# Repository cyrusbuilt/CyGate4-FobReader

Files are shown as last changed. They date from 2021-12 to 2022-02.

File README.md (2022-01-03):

# CyGate4-FobReader

Proximity Fob/Card reader add-on for CyGate4

## Synopsis

This is a proximity fob/card reader add-on for [CyGate4](https://github.com/cyrusbuilt/CyGate4).  It is designed to be a carrier board for the the [MiFare RC522](https://www.sunfounder.com/products/rfid-kit-red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). This device can read all fobs/cards supported by the MiFare MFRC522 and connects to the CyGate4 over I2C (aka 2-wire) bus. It can be powered by the CyGate4 itself or via an external 5VDC supply. This board can store up to 5 scanned cards in memory before overwriting the oldest scans. As scanned cards are read from the controller, they are removed from the buffer. Support for the CyGate4 Fob Reader is built-in to the CyGate4 firmware. This board uses a 7bit addressing scheme that allows up to 8 readers to be attached to a single CyGate4 at any given time. As long as the address is configured appropriately, they will be auto-detected and initialized during CyGate4's boot cycle.

## Operation

On power-up, the PWR LED will turn on and the device will immediately boot and log debug messages to the serial console. It will make itself available on the I2C bus (if connected) at the configured address. Presenting a MiFare-comptible prox card/fob will trigger a read. If a valid read occurs, the tag will be stored in memory.  When the read occurs, the ACT LED will flash once and the piezo will beep once.  This will happen whether it is connected to a CyGate4 host or not. If the tag sent to CyGate4 is determined to be invalid, it will send a command back indicating a bad card which will cause this reader to beep and flash 3 times in ~1 second.

## Configuration

The board has 3 jumpers (J4 - J6) that are used to configure the I2C bus address. Each jumper *MUST* be jumpered to either (+) (binary 1) or (-) (binary 0) and cannot be left open. The 3 values are bit-OR'ed together along with an address offset to compute the bus address.

## Command Set and Communication Protocol

The following commands can be sent to the device and will return a response. Since I have not timed each of the responses yet,
so as a general rule of thumb, I would allow at least 10ms between sending the command and expecting the response.

```
DETECT = 0xFA
INIT = 0xFB
GET_FIRMWARE = 0xFC
SELF_TEST = 0xDC
GET_TAGS = 0xFD
GET_AVAILABLE = 0xFE
BAD_CARD = 0xDD
GET_MIFARE_VERSION = 0xDB
```

DETECT: Asks the reader to identify itself. Sends back a one-byte ACK response if present: (DETECT_ACK = 0xDA).

INIT: Instructs the reader to initialize itself. Currently, this will only return a command ACK (INIT = 0xFB).

GET_FIRMWARE: This instructs the reader to report it's firmware version which will send the following packet:

```
Byte 0 = ACK (GET_FIRMWARE = 0xFC)
Byte 1 = Version length (# of bytes representing version string)
Byte 2 - n = The version string
```

SELF_TEST: Instructs the reader to perform a self-test. This will return a packet containing self-test result:

```
Byte 0 = ACK (SELF_TEST = 0xDC)
Byte 1 = Result (1 = Pass, 0 = Fail)
```

GET_TAGS: Instructs the reader to return any tags it has stored in memory (currently limited to 1 (the most recent) but will be up to 5 in the future). This will return the following packet data:

```
Byte 0 = ACK (GET_TAGS = 0xFD)
Byte 1 = Record count (1)
Byte 2 = Tag length in bytes (up to 10)
Byte 3 - 13 = Tag serial number (right-padded with 0xFF)
```

GET_AVAILABLE: Instructs the reader to indicate whether or not any tags are present. Sends back the following packet:

```
Byte 0 = ACK (GET_AVAILABLE = 0xFE)
Byte 1 = Result (1 = Available, 0 = No tags)
```

BAD_CARD: Instructs the reader to signal to the user that a bad card was presented (access denied). Sends back a one-byte ACK (BAD_CARD = 0xDD).

GET_MIFARE_VERSION: Instructs the reader to return the MiFare RFID reader version. Sends back the following packet:

```
Byte 0 = ACK (GET_MIFARE_VERSION = 0xDB)
Byte 1 = MiFare version (ie. 0x92)
```

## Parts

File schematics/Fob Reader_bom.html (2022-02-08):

Label | Part Type | Properties
Arduino Micro | Arduino Micro (Rev3) | type Arduino Micro (Rev3)
J1 | Generic female header - 8 pins | hole size 1.0mm,0.508mm; pins 8; form ♀ (female); package THT; pin spacing 0.1in (2.54mm); row single
J2 | Screw terminal - 4 pins | hole size 1.0mm,0.508mm; pins 4; package THT; pin spacing 0.137in (3.5mm)
J3 | Piezo Speaker
J4 | Generic male header - 3 pins | hole size 1.0mm,0.508mm; pins 3; form ♂ (male); package THT; pin spacing 0.1in (2.54mm); row single
J5 | Generic male header - 3 pins | hole size 1.0mm,0.508mm; pins 3; form ♂ (male); package THT; pin spacing 0.1in (2.54mm); row single
J6 | Generic male header - 3 pins | hole size 1.0mm,0.508mm; pins 3; form ♂ (male); package THT; pin spacing 0.1in (2.54mm); row single
J7 | Generic female header - 4 pins | hole size 1.0mm,0.508mm; pins 4; form ♀ (female); package THT; pin spacing 0.1in (2.54mm); row single
J8 | Generic female header - 4 pins | hole size 1.0mm,0.508mm; pins 4; form ♀ (female); package THT; pin spacing 0.1in (2.54mm); row single
LED1 | Red (633nm) LED | color Red (633nm); leg yes; package 5 mm [THT]
LED2 | Green (570nm) LED | color Green (570nm); leg yes; package 5 mm [THT]
Part2 | Schematic Frame | sheet 1/1; date 1609690318; project CyGate4 - Fob Reader; rev 2.0; filename Fob Reader.fzz; descr Proximity Fob Reader for CyGate4
Amount | Part Type | Properties
1 | Arduino Micro (Rev3) | type Arduino Micro (Rev3)
1 | Generic female header - 8 pins | hole size 1.0mm,0.508mm; pins 8; form ♀ (female); package THT; pin spacing 0.1in (2.54mm); row single
1 | Screw terminal - 4 pins | hole size 1.0mm,0.508mm; pins 4; package THT; pin spacing 0.137in (3.5mm)
1 | Piezo Speaker
3 | Generic male header - 3 pins | hole size 1.0mm,0.508mm; pins 3; form ♂ (male); package THT; pin spacing 0.1in (2.54mm); row single
2 | Generic female header - 4 pins | hole size 1.0mm,0.508mm; pins 4; form ♀ (female); package THT; pin spacing 0.1in (2.54mm); row single
1 | Red (633nm) LED | color Red (633nm); leg yes; package 5 mm [THT]
1 | Green (570nm) LED | color Green (570nm); leg yes; package 5 mm [THT]
1 | Schematic Frame | sheet 1/1; date 1609690318; project CyGate4 - Fob Reader; rev 2.0; filename Fob Reader.fzz; descr Proximity Fob Reader for CyGate4

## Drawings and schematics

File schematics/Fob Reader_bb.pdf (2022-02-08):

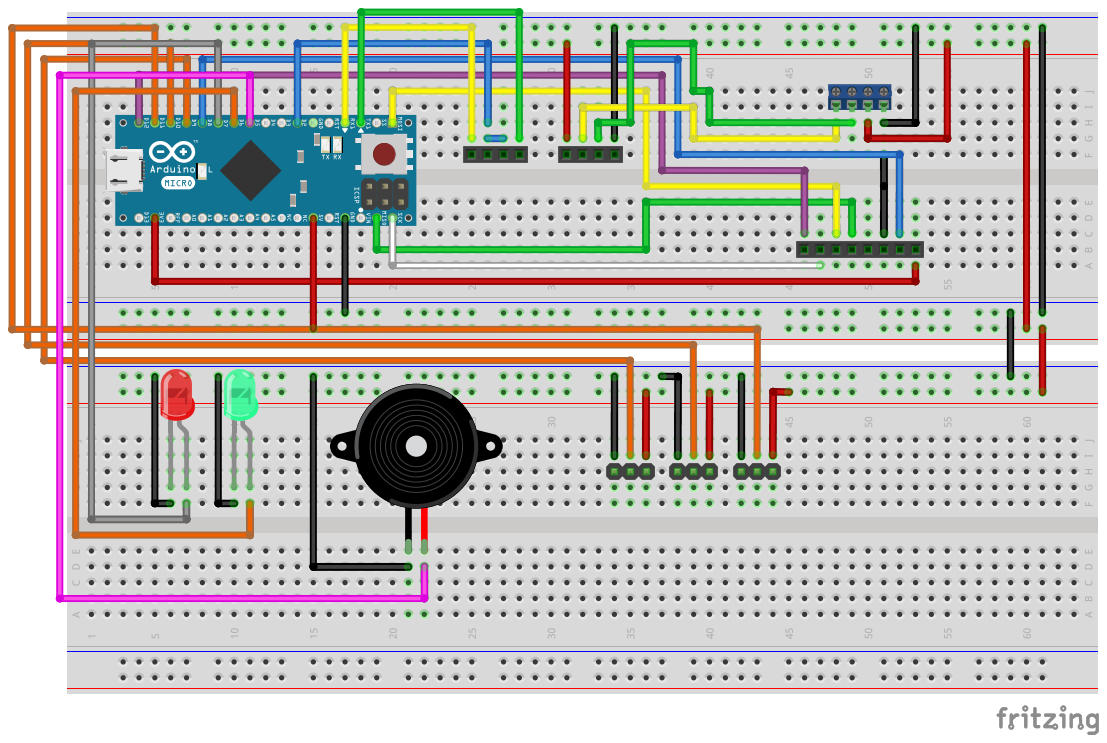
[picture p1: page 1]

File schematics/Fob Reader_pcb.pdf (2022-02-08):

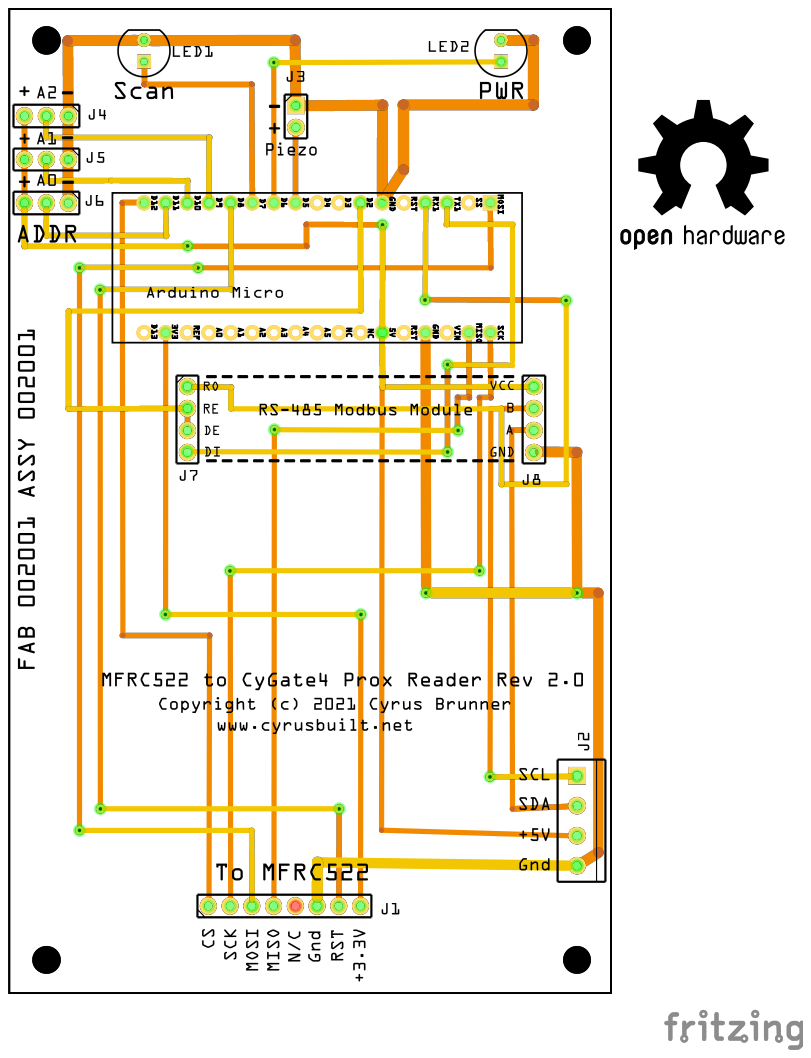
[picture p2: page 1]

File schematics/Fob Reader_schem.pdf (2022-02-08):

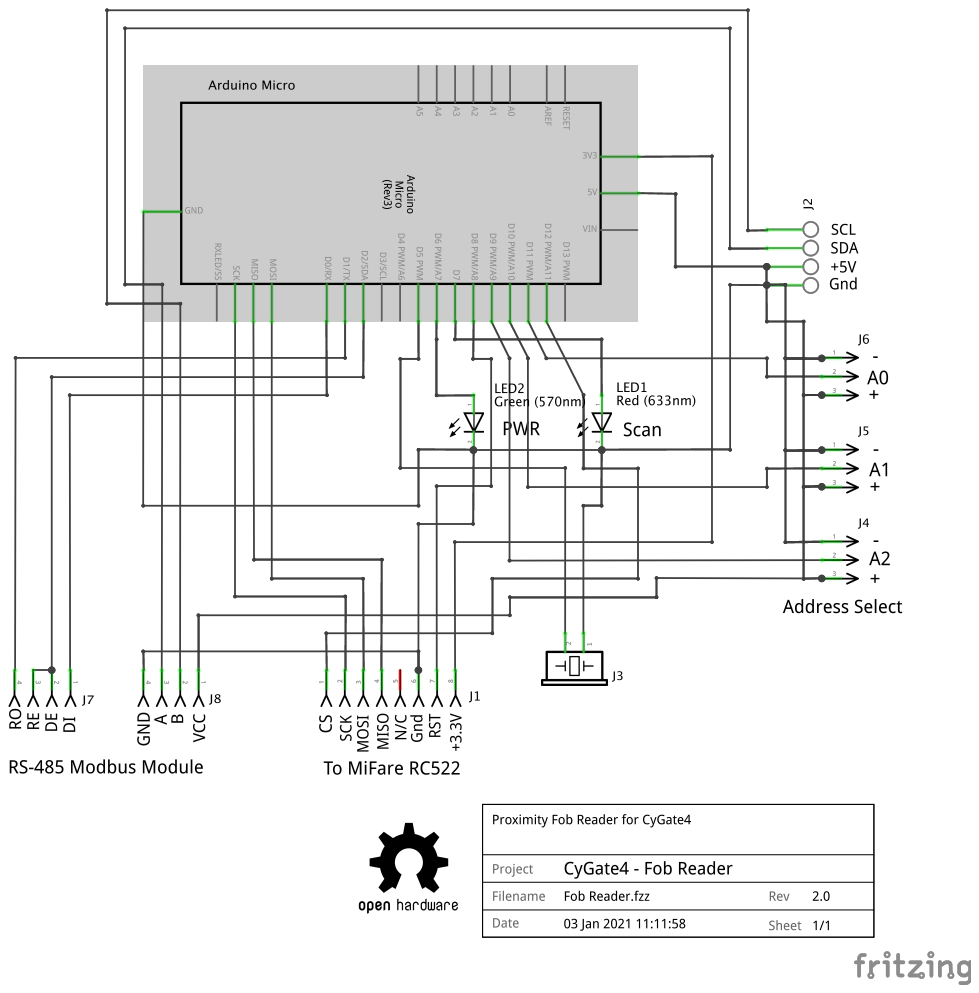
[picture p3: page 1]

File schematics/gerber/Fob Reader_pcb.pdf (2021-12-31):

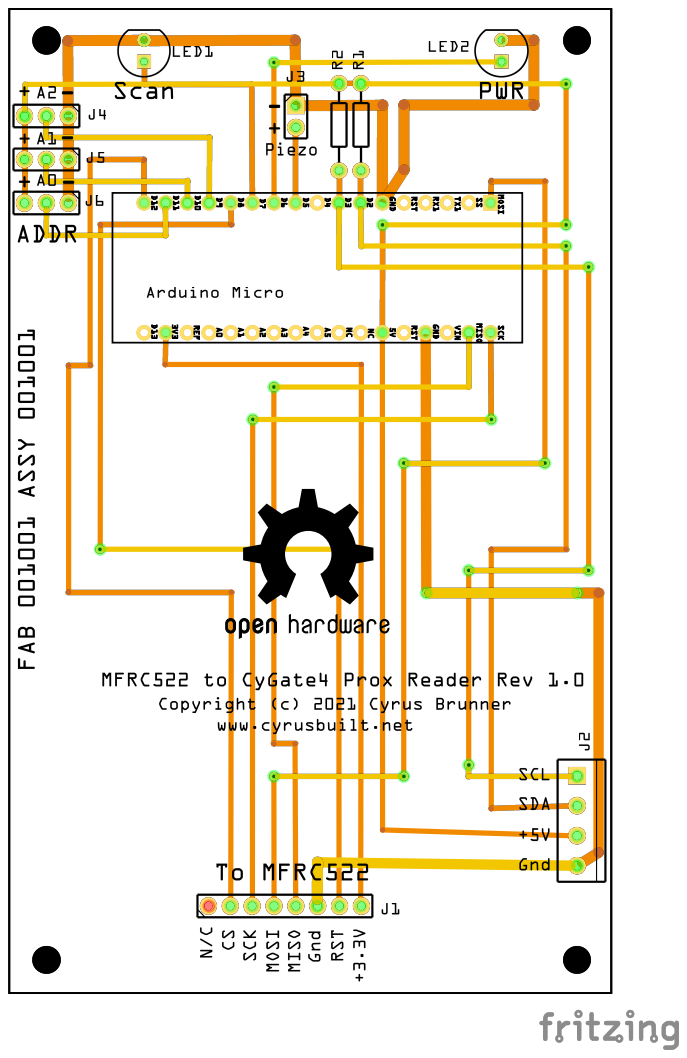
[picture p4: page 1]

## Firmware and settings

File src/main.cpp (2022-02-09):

/**
 * @file main.cpp
 * @author cyrus (cyrusbuilt at gmail dot com)
 * @brief Firmware for CyGate4 - Fob Reader.  Intended to run on the Arduino
 * Micro Rev3. Works with MiFare MFRC522 RFID readers and is intended to
 * interface with the CyGate4 over I2C.
 * @version 1.0
 * @date 2021-12-31
 * 
 * @copyright Copyright (c) Cyrus Brunner 2021
 * 
 */

#include <Arduino.h>
#include <SPI.h>
#include "LED.h"
#include "Buzzer.h"
#include "MFRC522.h"
#include "Modbus.h"

#define FIRMWARE_VERSION "1.0"

#define DEBUG_BAUD_RATE 9600
#define MODBUS_BAUD_RATE 115200
#define ADDRESS_BASE 0x10
#define MODBUS_HOST_ADDR 0

// Pin definitions
#define PIN_PWR_LED 7
#define PIN_ACT_LED 6
#define PIN_PIEZO 5
#define PIN_MFRC522_RESET 8
#define PIN_MFRC522_SS 12
#define PIN_ADDRESS_A0 11
#define PIN_ADDRESS_A1 10
#define PIN_ADDRESS_A2 9
#define PIN_MODBUS_ENABLE 2

// I2C packet data
#define DETECT_ACK 0xDA
#define TAG_PRESENCE_SIZE 2
#define TAG_PACKET_SIZE 14
#define TAG_DATA_SIZE 4
#define READER_FW_SIZE 2
#define SELF_TEST_SIZE 2

/**
 * @brief Possible device commands.
 */
enum class CommandType : byte {
	DETECT = 0xFA,
	INIT = 0xFB,
	GET_FIRMWARE = 0xFC,
	SELF_TEST = 0xDC,
	GET_TAGS = 0xFD,
	GET_AVAILABLE = 0xFE,
	BAD_CARD = 0xDD,
	GET_MIFARE_VERSION = 0xDB
};

// Global vars
LED pwrLED(PIN_PWR_LED, NULL);
LED actLED(PIN_ACT_LED, NULL);
Buzzer piezo(PIN_PIEZO, NULL, "");
MFRC522 reader(PIN_MFRC522_SS, PIN_MFRC522_RESET);
byte nuidPICC[TAG_DATA_SIZE];  // TODO Should this be volatile?
//volatile byte command = 0xFF;
//volatile bool processCommand = false;
const short addrPins[3] = {
	PIN_ADDRESS_A0,
	PIN_ADDRESS_A1,
	PIN_ADDRESS_A2
};

/**
 * @brief Print Hex values to the serial console
 * 
 * @param buffer The buffer containing the values to print.
 * @param bufferSize The buffer size.
 */
void printHex(byte *buffer, byte bufferSize) {
	for (byte i = 0; i < bufferSize; i++) {
    	Serial.print(buffer[i] < 0x10 ? " 0" : " ");
    	Serial.print(buffer[i], HEX);
  	}
}

/**
 * @brief Instructs the MFRC522 to execute a self-test.
 */
void performSelfTest() {
	// Serial.print(F("INFO: Performing self test ..."));
	bool result = reader.PCD_PerformSelfTest();
	// Serial.println(result ? F("PASS") : F("FAIL"));

	// Serial.println(F("INFO: Sending result"));
	byte packet[SELF_TEST_SIZE];
	packet[0] = (byte)CommandType::SELF_TEST;
	packet[1] = (byte)result;
	// Serial.print(F("DEBUG: Sending packet = "));
	// printHex(packet, SELF_TEST_SIZE);
	// Serial.println();
	Modbus.write(MODBUS_HOST_ADDR, packet, SELF_TEST_SIZE);
	delete[] packet;
}

/**
 * @brief Handles the bad-card signal from the CyGate4 host controller by
 * blinking the "ACT" LED and activating the piezo buzzer 3 times at 200ms
 * apart. 
 */
void badCard() {
	// Serial.println(F("ERROR: Host controller indicates bad card!"));
	byte response[1];
	response[0] = (byte)CommandType::BAD_CARD;
	// Serial.print(F("DEBUG: Sending response = 0x"));
	// Serial.println(response, HEX);
	Modbus.write(MODBUS_HOST_ADDR, response, 1);
	for (uint8_t i = 0; i < 3; i++) {
		actLED.on();
		piezo.on();
		delay(200);
		piezo.off();
		actLED.off();
	}

	delete[] response;
}

/**
 * @brief Clears the currently stored NUID (tag).
 */
void clearNUID() {
	for (size_t i = 0; i < sizeof(nuidPICC); i++) {
		nuidPICC[i] = 0x00;
	}
}

/**
 * @brief Sends an acknowledgement back to the host indicating that
 * we are, in fact, a CyGate4 Fob Reader and we are present.
 */
void sendDetectAck() {
	// Serial.println(F("INFO: Sending detect ACK."));
	byte response[1];
	response[0] = (byte)DETECT_ACK;
	// Serial.print(F("DEBUG: Sending response = 0x"));
	// Serial.println(response, HEX);
	Modbus.write(MODBUS_HOST_ADDR, response, 1);
	delete[] response;
}

/**
 * @brief Sends a packet containing the firmware version back to the host.
 */
void sendFirmware() {
	// Serial.println(F("INFO: Sending firmware version"));
	String fw = String(FIRMWARE_VERSION);
	int strBufLen = fw.length() + 1;
	byte strBuf[strBufLen];
	fw.getBytes(strBuf, strBufLen);

	size_t size = strBufLen + 2;
	
	byte* buffer = new byte[size];
	buffer[0] = (byte)CommandType::GET_FIRMWARE;
	buffer[1] = strBufLen;
	for (int i = 0; i < strBufLen; i++) {
		buffer[i + 2] = strBuf[i];
	}

	// Serial.print(F("DEBUG: sending bytes "));
	// for (size_t i = 0; i < size; i++) {
	// 	Serial.print(F("0x"));
	// 	Serial.print(buffer[i], HEX);
	// 	Serial.print(F(" "));
	// }

	// Serial.println();
	Modbus.write(MODBUS_HOST_ADDR, buffer, size);
	delete[] buffer;
}

bool hasTagData() {
	// Serial.print(F("DEBUG: Tag data: "));
	// printHex(nuidPICC, TAG_DATA_SIZE);
	// Serial.println();

	bool result = false;
	for (uint8_t i = 0; i < TAG_DATA_SIZE; i++) {
		if (nuidPICC[i] != 0x00) {
			result = true;
			break;
		}
	}

	return result;
}

/**
 * @brief Checks to see if a new tag is present.
 * 
 * @return true if a tag has been scanned that isn't stored in memory yet.
 * @return false if the tag has already been recently scanned.
 */
bool isNewTagPresent() {
	bool present = reader.uid.uidByte[0] != nuidPICC[0] || 
    	reader.uid.uidByte[1] != nuidPICC[1] || 
    	reader.uid.uidByte[2] != nuidPICC[2] || 
    	reader.uid.uidByte[3] != nuidPICC[3];
	Serial.print(F("DEBUG: Is new tag data = "));
	Serial.println(present ? F("Yes") : F("No"));
	return present;
}

/**
 * @brief Sends a packet to the host indicating a new tag is present.
 */
void sendTagPresence() {
	// Serial.println(F("INFO: Sending tag presence"));

	byte packet[TAG_PRESENCE_SIZE];
	packet[0] = (byte)CommandType::GET_AVAILABLE;
	packet[1] = (byte)hasTagData();

	// Serial.print(F("DEBUG: Sending packet: "));
	// printHex(packet, TAG_PRESENCE_SIZE);
	// Serial.println();
	
	Modbus.write(MODBUS_HOST_ADDR, packet, TAG_PRESENCE_SIZE);
	delete[] packet;
}

/**
 * @brief Sends the tag to the CyGate4 host over I2C.
 */
void sendCard() {
	//Serial.println(F("INFO: Sending card data"));
	byte packet[TAG_PACKET_SIZE];
	packet[0] = (byte)CommandType::GET_TAGS;
	packet[1] = 1;  // TODO Change this when we support more than one tag.
	packet[2] = TAG_DATA_SIZE;

	// Copy tag bytes
	for (uint8_t i = 0; i < packet[2]; i++) {
		packet[3 + i] = nuidPICC[i];
	}

	// Serial.print(F("DEBUG: Sending packet = "));
	// printHex(packet, TAG_PACKET_SIZE);
	// Serial.println();

	Modbus.write(MODBUS_HOST_ADDR, packet, TAG_PACKET_SIZE);
	delete[] packet;
	clearNUID();
}

/**
 * @brief Sends a packet to the host containing the RFID reader version.
 */
void sendMiFareVersion() {
	//Serial.println(F("INFO: Sending RFID reader version"));
	byte packet[READER_FW_SIZE];
	packet[0] = (byte)CommandType::GET_MIFARE_VERSION;
	packet[1] = reader.PCD_ReadRegister(MFRC522::VersionReg);

	// Serial.print(F("DEBUG: Sending packet = "));
	// printHex(packet, READER_FW_SIZE);
	// Serial.println();

	Modbus.write(MODBUS_HOST_ADDR, packet, READER_FW_SIZE);
	delete[] packet;
}

void sendInitAck() {
	byte buffer[1];
	buffer[0] = (byte)CommandType::INIT;
	Modbus.write(MODBUS_HOST_ADDR, buffer, 1);
	delete[] buffer;
}

/**
 * @brief Handles data received on the I2C bus.
 * @param byteCount The number of bytes received.
 */
// void commBusReceiveHandler(int byteCount) {
// 	// NOTE: We *should* only be recieving single-byte commands.
// 	command = Wire.read();
// 	processCommand = true;
// }

/**
 * @brief Handles requests received on the I2C bus and acknowledges valid
 * commands by sending the appropriate data back to the host.
 */
void handleCommand(byte command) {
	// if (!processCommand) {
	// 	return;
	// }

	// Serial.println(F("INFO: I2C request received"));
	// Serial.print(F("INFO: Received command: 0x"));
	// if (command < 16) {
	// 	Serial.print(F("0"));
	// }

	// Serial.println(command, HEX);
	// if (command == 0xFF) {
	// 	// We get a single 0xFF every time the host (master) device does a bus scan,
	// 	// sort of like the I2C equivalent of a 'ping'. We can just ignore these.
	// 	Serial.println(F("INFO: Bus scan from master"));
	// }

	
	switch (command) {
		case (byte)CommandType::INIT:
			// TODO Not sure exactly what to do here just yet.
			// Call setup() again?
			// Soft-reboot (asm jmp 0)?
			// Just re-init the reader?
			// For now, just ack.
			//Serial.println(F("INFO: Sending init ACK."));
			//Wire.write((byte)CommandType::INIT);
			sendInitAck();
			break;
		case (byte)CommandType::DETECT:
			sendDetectAck();
			break;
		case (byte)CommandType::GET_FIRMWARE:
			sendFirmware();
			break;
		case (byte)CommandType::SELF_TEST:
			performSelfTest();
			break;
		case (byte)CommandType::GET_TAGS:
			sendCard();
			break;
		case (byte)CommandType::BAD_CARD:
			badCard();
			break;
		case (byte)CommandType::GET_AVAILABLE:
			sendTagPresence();
			break;
		case (byte)CommandType::GET_MIFARE_VERSION:
			sendMiFareVersion();
			break;
		default:
			// Serial.print(F("WARN: Unrecognized command received: 0x"));
			// Serial.println(command, HEX);
			break;
	}

	//processCommand = false;
}

/**
 * @brief Retrieves card/fob details from the reader and dumps the details
 * to the serial console.
 */
void getCardInfo() {
	Serial.println(F("INFO: Read card info: "));
	reader.PICC_DumpDetailsToSerial(&reader.uid);
}

/**
 * @brief Checks to see if a compatible RFID tag was scanned.
 * @return true if a compatible tag was scanned.
 * @return false if an incompatible tag was scanned.
 */
bool isValidPiccType() {
	Serial.print(F("INFO: PICC type: "));
  	MFRC522::PICC_Type piccType = reader.PICC_GetType(reader.uid.sak);
  	Serial.println(reader.PICC_GetTypeName(piccType));

	// Check is the PICC of Classic MIFARE type
  	if (piccType != MFRC522::PICC_TYPE_MIFARE_MINI &&  
    	piccType != MFRC522::PICC_TYPE_MIFARE_1K &&
    	piccType != MFRC522::PICC_TYPE_MIFARE_4K) {
    	Serial.println(F("ERROR: Tag is not of type MIFARE Classic."));
    	return false;
  	}

	return true;
}

/**
 * @brief Reads new tags and stores them in the buffer. If the read tag
 * already exists in the internal buffer, then it is ignored.
 */
void readNewTag() {
	if (isNewTagPresent()) {
    	Serial.println(F("INFO: New card detected."));

		// Store NUID into nuidPICC array
    	for (uint8_t i = 0; i < TAG_DATA_SIZE; i++) {
      		nuidPICC[i] = reader.uid.uidByte[i];
    	}

		Serial.print(F("INFO: The NUID tag is (hex): "));
    	printHex(reader.uid.uidByte, reader.uid.size);
		Serial.println();
	}
	else {
		Serial.println(F("WARN: Card read previously."));
	}
}

/**
 * @brief Puts the RFID reader in idle mode.
 */
void idleReader() {
	reader.PICC_HaltA();
	reader.PCD_StopCrypto1();
}

int getDeviceAddress() {
	byte addressOffset = 0;
	for (uint8_t i = 0; i < 3; i++) {
		pinMode(addrPins[i], INPUT_PULLUP);
		delay(1);

		addressOffset <<= 1;
		if (digitalRead(addrPins[i]) == HIGH) {
			addressOffset |= 0x01;
		}
	}

	int busAddress = ADDRESS_BASE + addressOffset;
	return busAddress;
}

void onReceiveHandler(ModbusPacket* packet) {
	if (packet->payloadSize == 1) {
		// We should only be getting single-byte commands.
		handleCommand(packet->payload[0]);
	}
}

/**
 * @brief Initializes the RS-232 serial console.
 */
void initSerial() {
	Serial.begin(DEBUG_BAUD_RATE);
	while (!Serial) {
		delay(1);
	}

	Serial.print(F("INIT: CyGate4-FobReader v"));
	Serial.print(FIRMWARE_VERSION);
	Serial.println(F(" booting..."));
}

/**
 * @brief Initializes outputs (LEDs, piezo). 
 */
void initOutputs() {
	Serial.print(F("INIT: Initializing output devices ..."));
	pwrLED.init();
	pwrLED.on();

	actLED.init();
	actLED.off();

	piezo.init();
	piezo.off();
	Serial.println(F("DONE"));
}

/**
 * @brief Initializes the SPI bus and the MFRC522.
 */
void initReader() {
	Serial.print(F("INIT: Initializing MFRC522 ..."));
	SPI.begin();
	reader.PCD_Init();
	delay(4);
	Serial.println(F("DONE"));
	Serial.print(F("INIT: "));
	reader.PCD_DumpVersionToSerial();
}


void initModbus() {
	int address = getDeviceAddress();
	Serial.print(F("INIT: Initializing modbus on address 0x"));
	Serial.print(address, HEX);
	Serial.print(F(" ..."));
	Serial1.begin(MODBUS_BAUD_RATE);
	Modbus.begin(&Serial1, address, PIN_MODBUS_ENABLE);
	Modbus.setOnRecieve(onReceiveHandler);
	Serial.println(F("DONE"));
}

/**
 * @brief Initializes the I2C communication bus which allows the CyGate4 host
 * controller to connect.
 */
// void initCommBus() {
// 	Serial.print(F("INIT: Initializing I2C comm bus... "));

// 	byte addressOffset = 0;
// 	for (uint8_t i = 0; i < 3; i++) {
// 		pinMode(addrPins[i], INPUT_PULLUP);
// 		delay(1);

// 		addressOffset <<= 1;
// 		if (digitalRead(addrPins[i]) == HIGH) {
// 			addressOffset |= 0x01;
// 		}
// 	}

// 	int busAddress = ADDRESS_BASE + addressOffset;
// 	Wire.begin(busAddress);
// 	Wire.onReceive(commBusReceiveHandler);
// 	Wire.onRequest(commBusRequestHandler);
	
// 	Serial.println(F("DONE"));
// 	Serial.print(F("INIT: I2C bus address: "));
// 	Serial.println(busAddress, HEX);
// }

/**
 * @brief Boot sequence. Initializes the firmware.
 */
void setup() {
	initSerial();
	initOutputs();
	initReader();
	//initCommBus();
	initModbus();
	Serial.println(F("INIT: Boot sequence complete."));
}

/**
 * @brief Main program loop. Checks for new cards being presented to the reader.
 */
void loop() {
	Modbus.loop();
	if (!reader.PICC_IsNewCardPresent() || !reader.PICC_ReadCardSerial()) {
		return;
	}

	piezo.on();
	actLED.on();

	getCardInfo();
	if (!isValidPiccType()) {
		piezo.off();
		actLED.off();
		return;
	}

	readNewTag();

	piezo.off();
	actLED.off();
	idleReader();
}

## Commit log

2021-01-13 Initial release of hardware design
    [Fob Reader.fzz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]
2021-12-31 Minor design changes and added firmware.
    [Fob Reader.fzz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]
2022-01-17 Fix reader pinout and I2C init routine
    [Fob Reader.fzz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]
2022-01-20 Fixing I2C communication
2022-02-08 Redesign to use RS-485 instead of I2C
    [Fob Reader.fzz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]
